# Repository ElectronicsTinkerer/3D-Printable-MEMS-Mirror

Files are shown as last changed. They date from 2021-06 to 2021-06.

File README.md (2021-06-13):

# 3D-Printable-MEMS-Mirror
Files for a 3D-printable MEMS mirror.

## Files
* `models` - SolidWorks files for parts
* `stls` - STL files for printing
* `arduino` - Arduino controller code
* `kicad` - PCB files (and gerbers)

## Online Resources
* [MDPI Books, _MEMS Mirrors_ ](https://www.mdpi.com/books/pdfview/book/611) - Great PDF of a lot of different MEMS mirrors designs and analysis.
* Shopping (For commercial MEMS Mirrors):
  * [Mirrorcle Technologies Inc.](https://www.mirrorcletech.com/wp/products/mems-mirrors/) - Has pricing info
  * [Preciseley Microtechnology Corp.](https://preciseley.com/products/) - Even has development hats for RPi!
  * [Hamamatsu](https://www.hamamatsu.com/us/en/product/optical-components/mems-mirror/index.html)

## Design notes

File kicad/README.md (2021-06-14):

# Axis Drivers for Mirrors

## Interface
### Power
Each board has a 16-30v DC, single rail input. This is the operating voltage of the output amplifiers.

### Output
At the end of the board is the output terminal block to be connected to one of the yoke's deflection coils.

### Digital Interface
At the other end is a parallel interface header for sending data to the DAC. The DAC operates over a 5v interface and all connections have 10k pullup resistors, meaning that unused inputs can be left unconnected. There is a 12-bit parallel data bus, read/write, chip select, reset, and load inputs.

## Output Drive Design
In order to achieve a differential output, two output amplifiers are used, one the inversion of the other around 0.5 * VCC.

## Known Issues
* The heatsinks currently on the KiCad boards are inadequate for the output amplifiers if running at greater than about 0.5A output current. (Active cooling is required)
* The 2.5V regulator's pinning is rotated 120 degrees clockwise from what it should be, so check the datasheet and schematic before soldering. This should be fixed some time in the future.

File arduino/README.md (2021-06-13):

# Arduino Controller for Mirror

## Pin Connections

Pin | Signal Name | Description
--- | --- | ---
`0` | `D0` | Digital 0
`1` | `D1` | Digital 1
`2` | `D2` | Digital 2
`3` | `D3` | Digital 3
`5` | `D5` | Digital 4
`4` | `D4` | Digital 5
`6` | `D6` | Digital 6
`7` | `D7` | Digital 7
`8` | `LD` | Load latch to DAC
`9` | `V_CS` | Select vertical DAC
`10` | `H_CS` | Select horizontal DAC

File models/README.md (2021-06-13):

# MEMS Mirror Design Files

## Files
* `Mirror-Gimbal` - Original 2-axis galvanometer design
* `Mirror-Gimbal-v1.1` - Minor update
* `Mirror-Gimbal-v1.2` - Increased torsion arm length
* `Mirror-Gimbal-v2` - Original 2-axis with vertical magnet mounts
* `Mirror-Gimbal-V3` - Uses quad "O" supports (0.5mm width)
* `Mirror-Gimbal-V3-0.6mm` - Quad "O" supports (0.6mm width)
* `MDD-BoardMount` - Mount for holding deflection driver PCBs and magnetic deflection yoke.

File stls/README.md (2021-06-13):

# MEMS Mirror STLs

## Progression
Photo of each iteration of the mirror gimbal design


## Files
* `Mirror-Gimbal` - Original 2-axis galvanometer design
* `Mirror-Gimbal-v1.1` - Minor update
* `Mirror-Gimbal-v1.2` - Increased torsion arm length
* `Mirror-Gimbal-v2` - Original 2-axis with vertical magnet mounts
* `Mirror-Gimbal-V3` - Uses quad "O" supports (0.5mm width)
* `Mirror-Gimbal-V3-0.6mm` - Quad "O" supports (0.6mm width)
* `MDD-BoardMount` - Mount for holding deflection driver PCBs and magnetic deflection yoke.

## Printer Settings

### Mirror Gimbals
* Initial layer height should be set to `0.25mm`
* Bottom layer should be printed as `concentric`

### Everything Else
* Pretty much whatever works on your printer

## Assembling
The mirror gimbals should be printed with the above settings.
Use superglue to attach a small neodymium magnet to the back (inside) of the central disk on the gimbal. The smaller the magnet, the less mass of the overall system, and thus an increased resonant (and operating) frequency. The disadvantage to a smaller magnet is its weaker magnetic field, meaning that a larger external field must be applied to achieve the same deflection.
For the mirrors, I cut out squares from a dead HDD platter, which were then superglued onto the top of the gimbal's central disk. (For reference, the mirror for gimbal 4C is about 2mm square while 4A's mirror is about 7mm square.)

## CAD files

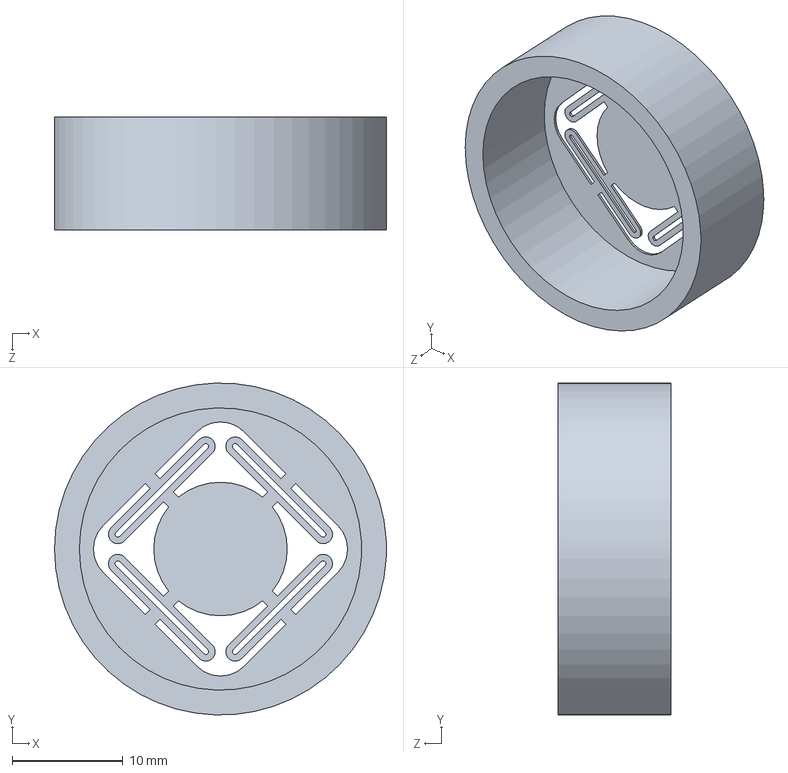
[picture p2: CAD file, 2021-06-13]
models/Mirror-Gimbal-V3.SLDPRT
30.0 x 30.0 x 10.2 mm

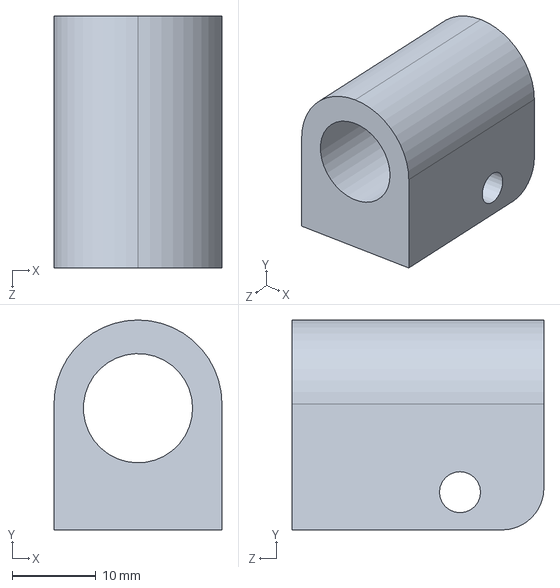
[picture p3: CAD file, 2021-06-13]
models/MDD-LaserHousing.SLDPRT
20.0 x 25.0 x 30.0 mm

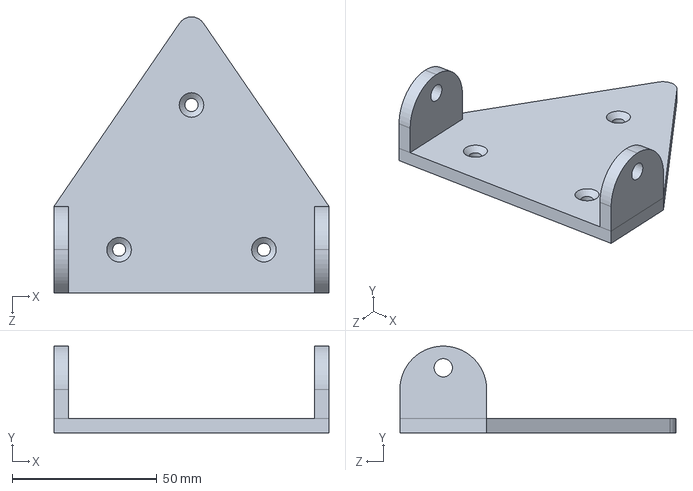
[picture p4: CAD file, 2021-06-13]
models/MDD-Rocker.SLDPRT
95.0 x 30.0 x 95.4 mm

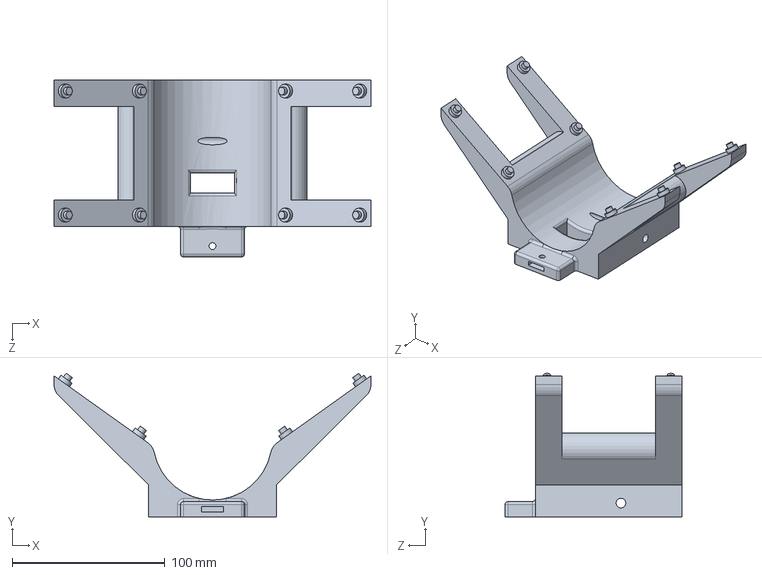
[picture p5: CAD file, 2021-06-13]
models/MDD-BoardMount.SLDPRT
207.8 x 94.2 x 116.0 mm

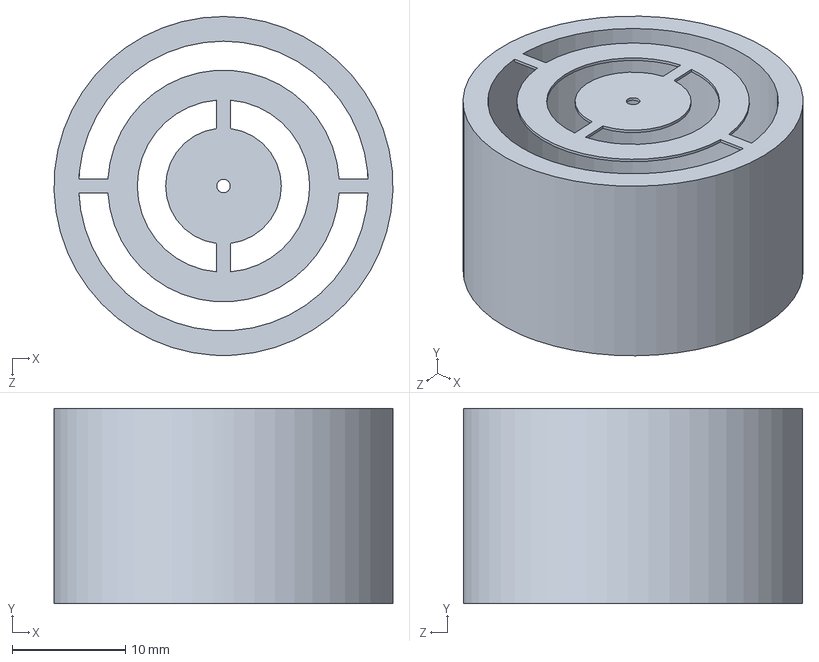
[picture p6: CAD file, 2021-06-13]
models/Mirror-Gimbal.SLDPRT
30.0 x 17.3 x 30.0 mm

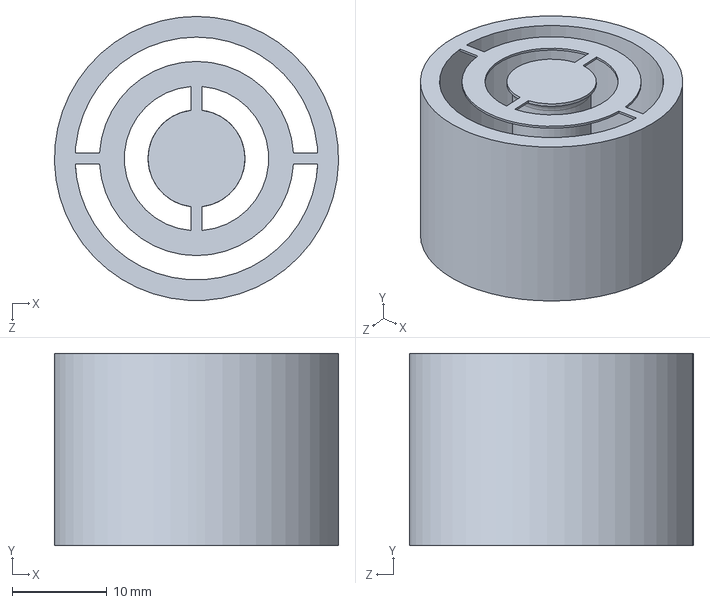
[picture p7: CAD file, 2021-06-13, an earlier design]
models/Mirror-Gimbal-V2.SLDPRT
30.0 x 20.3 x 30.0 mm

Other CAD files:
stls/Mirror-Gimbal-V3-0.6mm.STL
models/Mirror-Gimbal-v1.1.SLDPRT
models/Mirror-Gimbal-v1.2.SLDPRT
stls/MDD-BoardMount.STL
stls/Mirror-Gimbal-V2.STL
stls/Mirror-Gimbal-V3.STL
stls/Mirror-Gimbal-v1.1.STL
stls/Mirror-Gimbal-v1.2.STL
stls/Mirror-Gimbal.STL

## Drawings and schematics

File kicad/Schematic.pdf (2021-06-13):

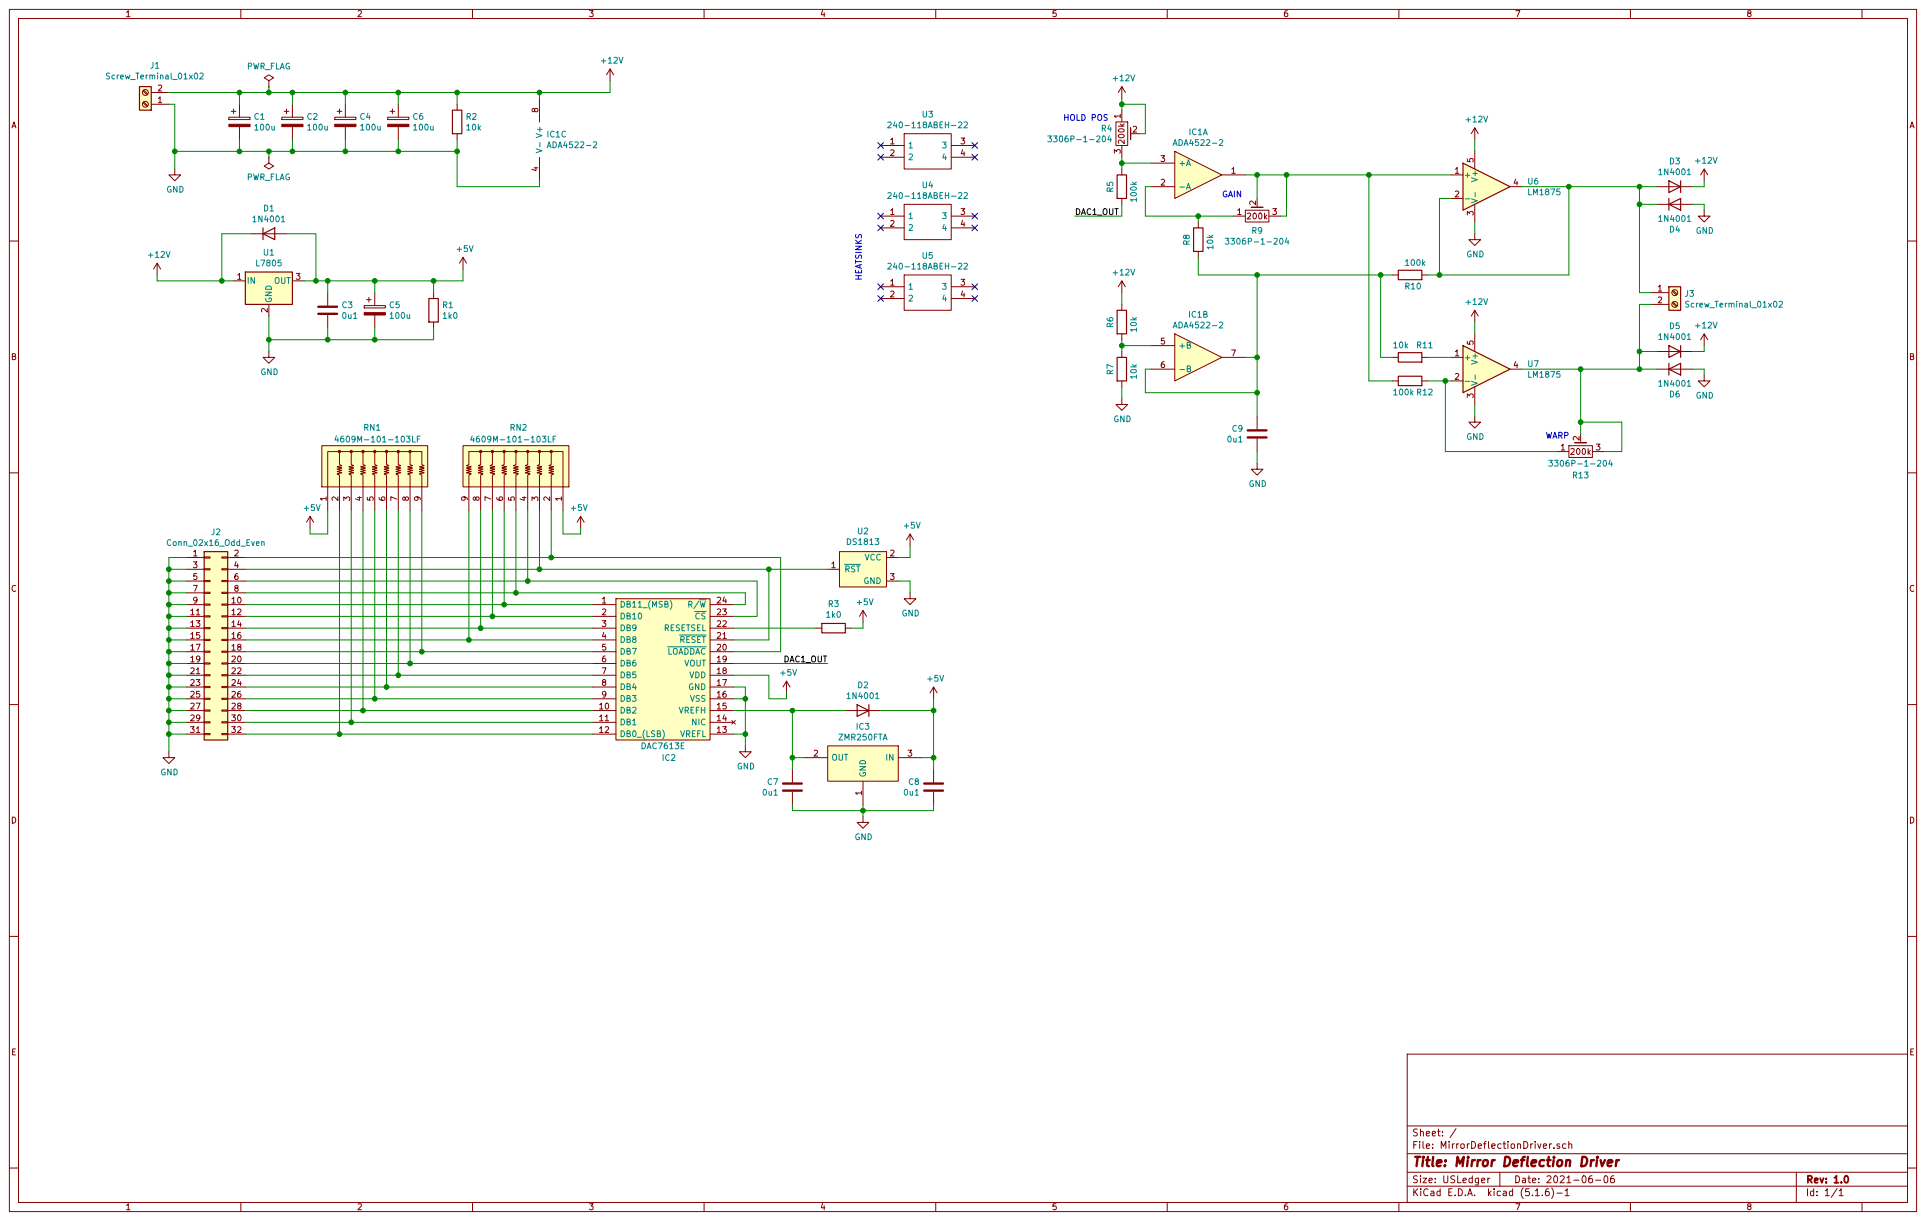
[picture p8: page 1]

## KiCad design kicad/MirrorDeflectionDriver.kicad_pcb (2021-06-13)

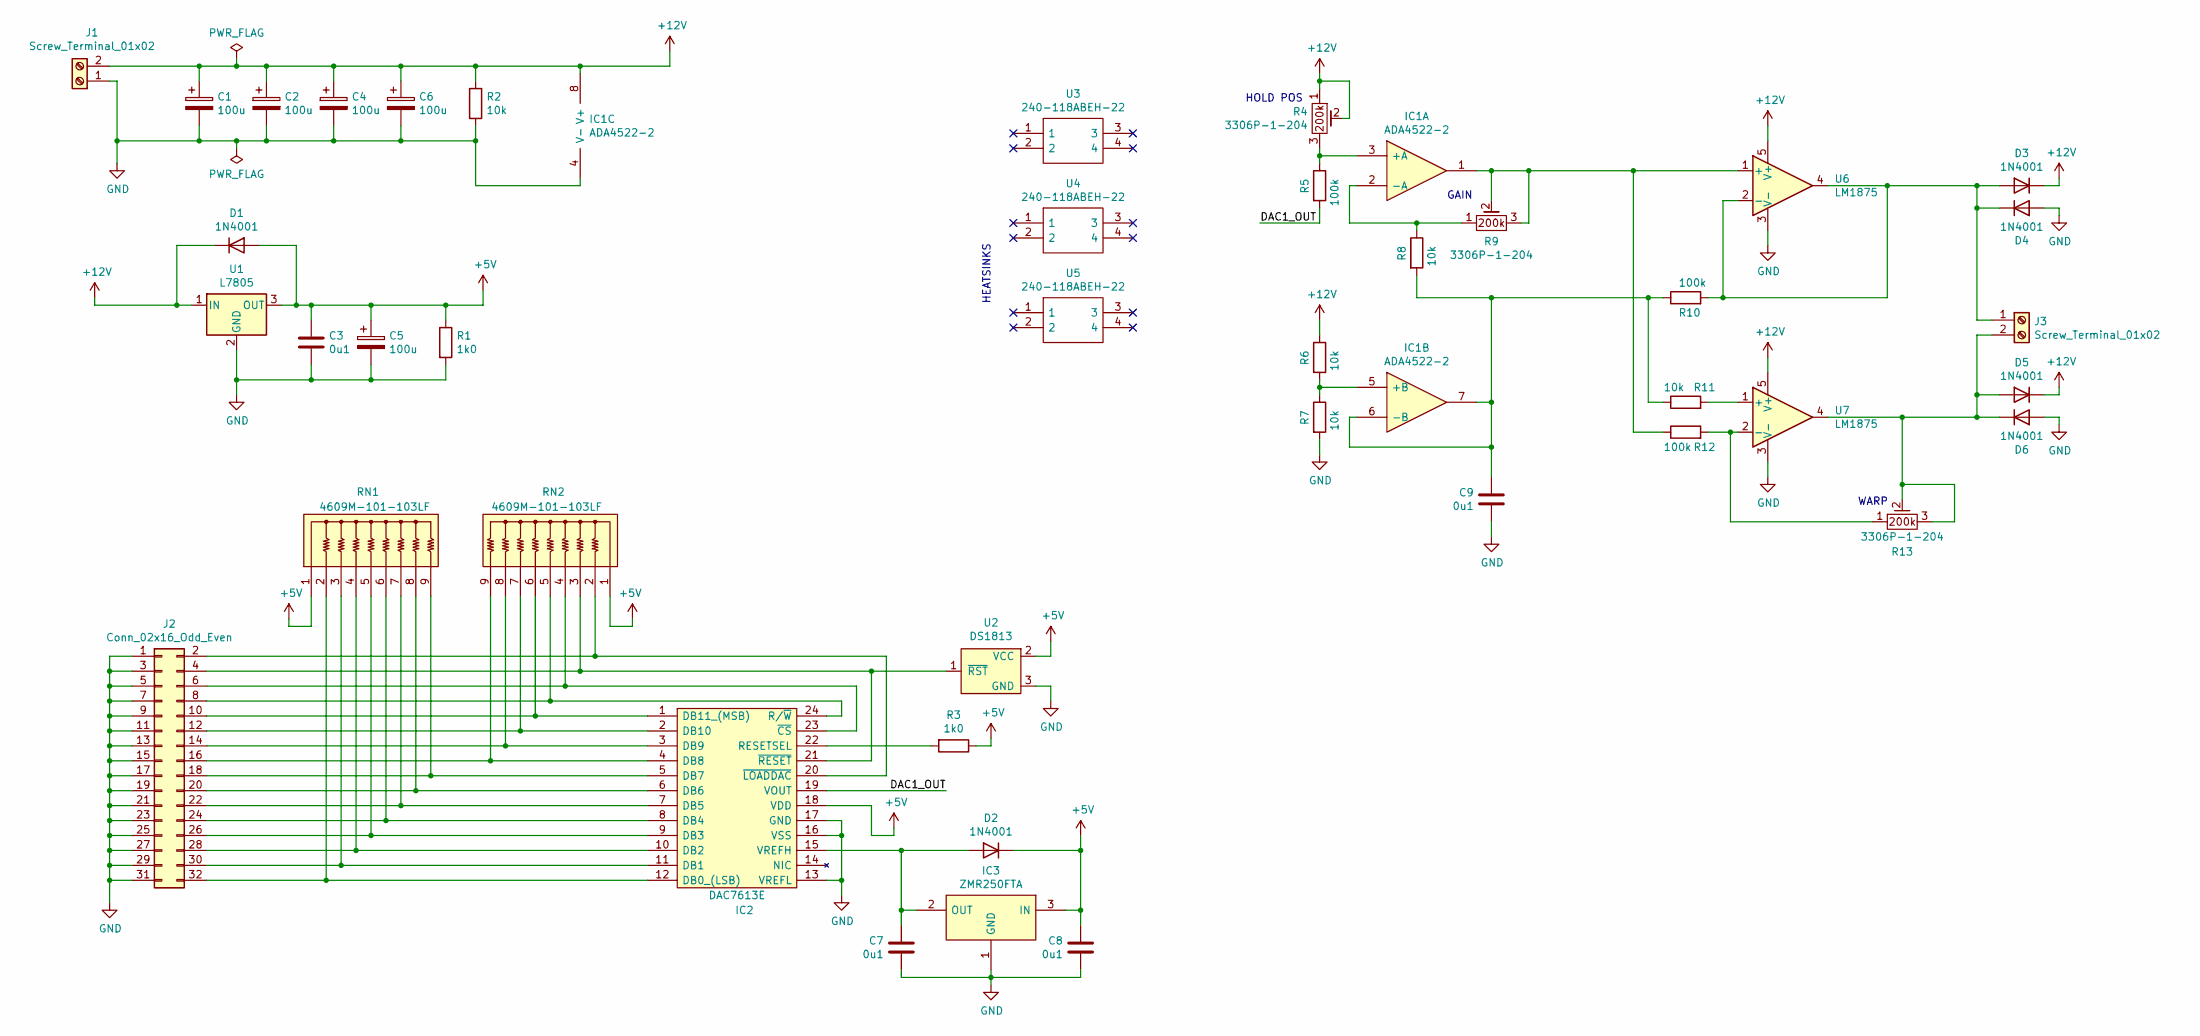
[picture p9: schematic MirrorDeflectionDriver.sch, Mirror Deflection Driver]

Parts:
C1, C2, C4, C5, C6: 100u; CP_Radial_D8.0mm_P3.50mm
C3, C7, C8, C9: 0u1; C_Disc_D4.3mm_W1.9mm_P5.00mm
D1, D2, D3, D4, D5, D6: 1N4001; D_DO-41_SOD81_P10.16mm_Horizontal
IC1: ADA4522-2; MSOP-8_3x3mm_P0.65mm; Mouser Part Number 584-ADA4522-2
IC2: DAC7613E; SOP65P780X200-24N; Mouser Part Number 595-DAC7613E
IC3: ZMR250FTA; SOT96P240X100-3N; Mouser Part Number 522-ZMR250FTA
J1, J3: Screw_Terminal_01x02; TerminalBlock_bornier-2_P5.08mm
J2: Conn_02x16_Odd_Even; PinHeader_2x16_P2.54mm_Vertical
R1, R3: 1k0; R_Axial_DIN0207_L6.3mm_D2.5mm_P7.62mm_Horizontal
R2, R6, R7, R8, R11: 10k; R_Axial_DIN0207_L6.3mm_D2.5mm_P7.62mm_Horizontal
R4, R9, R13: 3306P-1-204; 3306P1204; Mouser Part Number 652-3306P-1-204
R5, R10, R12: 100k; R_Axial_DIN0207_L6.3mm_D2.5mm_P7.62mm_Horizontal
RN1, RN2: 4609M-101-103LF; 4609X; Mouser Part Number 652-4609M-1LF-10K
U1: L7805; TO-126-3_Vertical
U2: DS1813; TO-92
U3, U4, U5: 240-118ABEH-22; 240118ABEH22; Mouser Part Number 567-240-118ABH-22
U6, U7: LM1875; TO-220-5_P3.4x3.7mm_StaggerOdd_Lead3.8mm_Vertical

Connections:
+5V: C3.1, C5.1, C8.1, D1.2 (A), D2.1 (K), IC2.18 (VDD), IC3.3 (IN), R1.1, R3.1, RN1.1, RN2.1, U1.3 (OUT), U2.2 (VCC)
+12V: C1.1, C2.1, C4.1, C6.1, D1.1 (K), D3.1 (K), D5.1 (K), IC1.8 (V+), J1.2, R2.1, R4.1, R4.2, R6.1, U1.1 (IN), U6.5 (V+), U7.5 (V+)
/DAC1_OUT: IC2.19 (VOUT), R5.2
GND: C1.2, C2.2, C3.2, C4.2, C5.2, C6.2, C7.2, C8.2, C9.2, D4.2 (A), D6.2 (A), IC1.4 (V-), IC2.13 (VREFL), IC2.16 (VSS), IC2.17 (GND), IC3.1 (GND), J1.1, J2.1, J2.3, J2.5, J2.7, J2.9, J2.11, J2.13, J2.15, J2.17, J2.19, J2.21, J2.23, J2.25, J2.27, J2.29, J2.31, R1.2, R2.2, R7.2, U1.2 (GND), U2.3 (GND), U6.3 (V-), U7.3 (V-)
unnamed: C7.1, D2.2 (A), IC2.15 (VREFH), IC3.2 (OUT)
unnamed: C9.1, IC1.6 (-B), IC1.7, R8.2, R10.1, R11.1
unnamed: D3.2 (A), D4.1 (K), J3.1, R10.2, U6.2 (-), U6.4
unnamed: D5.2 (A), D6.1 (K), J3.2, R13.2, R13.3, U7.4
unnamed: IC1.1, R9.2, R9.3, R12.1, U6.1 (+)
unnamed: IC1.2 (-A), R8.1, R9.1
unnamed: IC1.3 (+A), R4.3, R5.1
unnamed: IC1.5 (+B), R6.2, R7.1
unnamed: IC2.1 (DB11_(MSB)), J2.10, RN2.6
unnamed: IC2.2 (DB10), J2.12, RN2.7
unnamed: IC2.3 (DB9), J2.14, RN2.8
unnamed: IC2.4 (DB8), J2.16, RN2.9
unnamed: IC2.5 (DB7), J2.18, RN1.9
unnamed: IC2.6 (DB6), J2.20, RN1.8
unnamed: IC2.7 (DB5), J2.22, RN1.7
unnamed: IC2.8 (DB4), J2.24, RN1.6
unnamed: IC2.9 (DB3), J2.26, RN1.5
unnamed: IC2.10 (DB2), J2.28, RN1.4
unnamed: IC2.11 (DB1), J2.30, RN1.3
unnamed: IC2.12 (DB0_(LSB)), J2.32, RN1.2
unnamed: IC2.20 (~LOADDAC), J2.2, RN2.2
unnamed: IC2.21 (~RESET), J2.4, RN2.3, U2.1 (~RST)
unnamed: IC2.22 (RESETSEL), R3.2
unnamed: IC2.23 (~CS), J2.6, RN2.4
unnamed: IC2.24 (R/~W), J2.8, RN2.5
unnamed: R11.2, U7.1 (+)
unnamed: R12.2, R13.1, U7.2 (-)

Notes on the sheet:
GAIN
HOLD POS
WARP
HEATSINKS

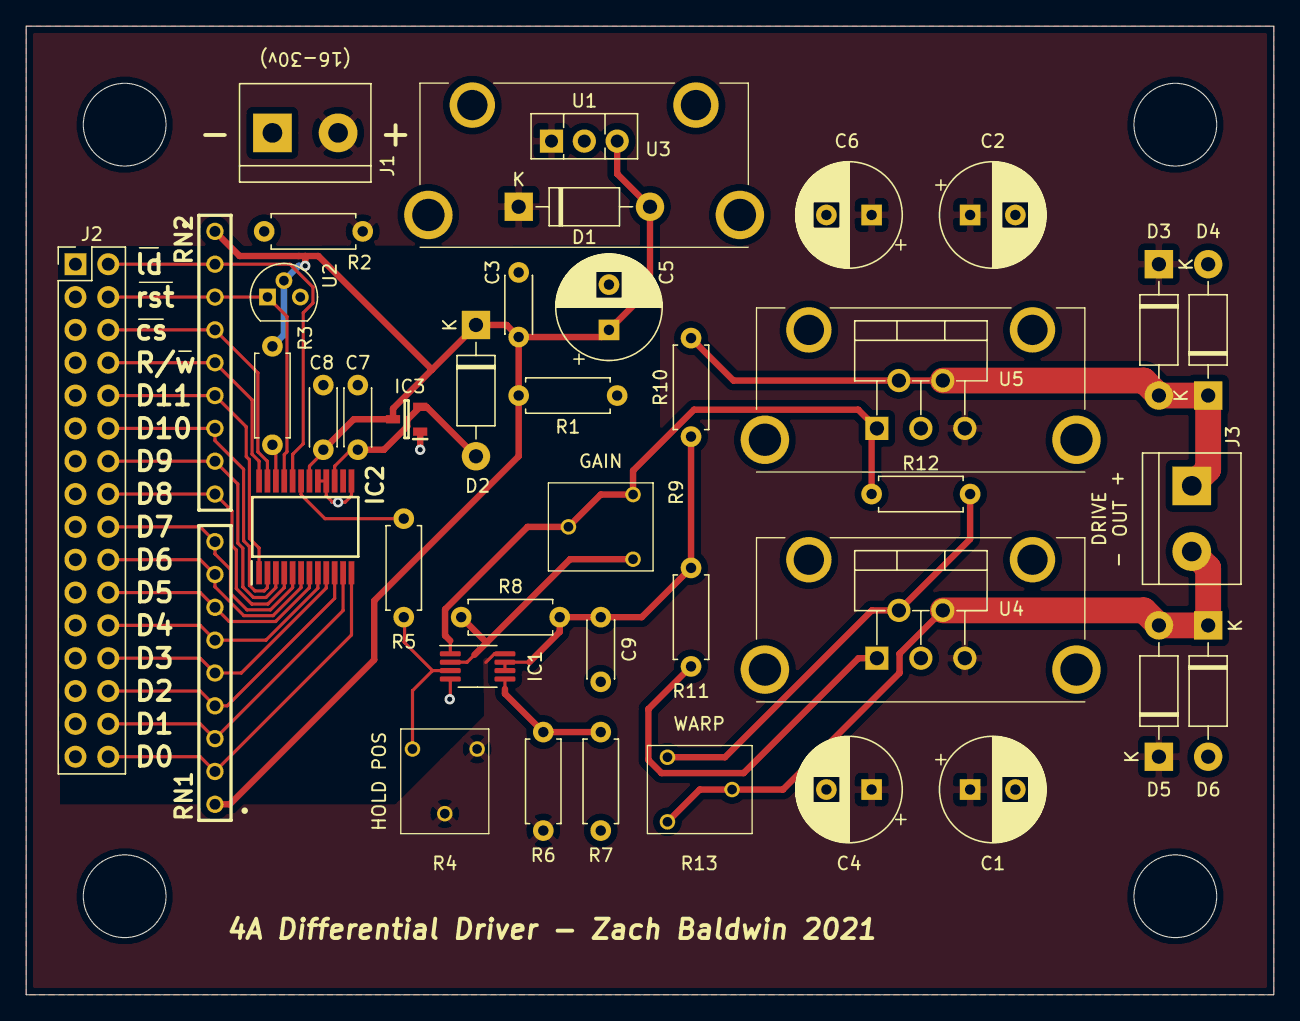
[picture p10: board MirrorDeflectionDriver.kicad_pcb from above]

Board: 2 copper layers, 96.5 x 74.9 mm, 43 parts (0 on the bottom side), 31 nets.

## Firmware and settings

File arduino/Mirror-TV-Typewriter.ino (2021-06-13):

#include <math.h>
#include <stdint.h>

#define VERT 0
#define HORZ 1

#define LD 8
#define V_CS 9
#define H_CS 10

#define STEP_DELAY 1000

#define LETTER_END {0, 0, 0}
#define IS_LETTER_END(li, i) (LETTERS[li][i][0] == 0 && LETTERS[li][i][1] == 0)

const int8_t LETTERS[][8][3] = {
  { {10, 0, 1}, {-10, -10, 1}, {10, 0, 1}, {-10, 10, 1}, LETTER_END }, // Z
  { {10, 0, 1}, {-10, 0, 1}, {0, -10, 1}, {10, 0, 1}, {-10, 0, 1}, {0, 10, 1}, LETTER_END },
  { {10, 0, 1}, {-10,  0, 1}, {10, 10, 1}, {-10, -10, 1}, {0, 10, 1}, {0, -10, 1}, LETTER_END }, // TESTING
  { {10, 10, 1}, {-20, -20, 1}, {10, 10, 1}, {10, 0, 1}, {-10, 0, 1}, LETTER_END },
  { {10, 0, 1}, {-10, -10, 1}, {10, 0, 1}, {-10, 0, 1}, {0, 10, 1}, LETTER_END },
  { {3, 12, 1}, {3, -12, 1}, {-1, 4, 1}, {-4, 0, 1}, {-1, -4, 1}, LETTER_END }, // 5 - SPACESHIP
  { {10, 0, 1}, {0, 10, 1}, {-10, 0, 1}, {0, -10, 1}, LETTER_END }, // 6 - SQUARE
  { {50, 50, 1}, {-50, -50, 1}, LETTER_END }
};

byte letter = 0;
int8_t x_pos = 0, y_pos = 0;

void initDAC() {
  for (int i = 0; i < 8; i++)
    pinMode(i, OUTPUT);
  pinMode(LD, OUTPUT); // /LD signal
  pinMode(V_CS, OUTPUT); // /CS for Vertical
  pinMode(H_CS, OUTPUT); // /CS for Hirizontal
 
  digitalWrite(LD, HIGH);
  digitalWrite(V_CS, HIGH);
  digitalWrite(H_CS, HIGH);
}

void writePos() {
//  Serial.println(y_pos + 0x80, HEX);
  writeAxis(x_pos + 0x80, HORZ);
  writeAxis(y_pos + 0x80, VERT);
    
  digitalWrite(LD, LOW); // LoaD in value to DAC
  delayMicroseconds(1);
  digitalWrite(LD, HIGH);
  delayMicroseconds(1);
}

inline void writeAxis(byte val, byte axis) {
  if (axis == VERT) {
    digitalWrite(V_CS, LOW);
    writeDAC(val);
    digitalWrite(V_CS, HIGH);
  }
  else if (axis == HORZ) {
    digitalWrite(H_CS, LOW);
    writeDAC(val);
    digitalWrite(H_CS, HIGH);
  }
}

inline void writeDAC(byte val) {
  for (int i = 0; i < 8; i++)
    digitalWrite(i, val & (1 << i));
}


// Bresenham's Algorithm (Wikipedia and middle-engine.com)
void nextLetter(byte letter_index) {
  for (uint8_t i = 0; i < 8 && !IS_LETTER_END(letter_index, i); i++) {
    
    int8_t end_x = x_pos + LETTERS[letter_index][i][0];
    int8_t end_y = y_pos + LETTERS[letter_index][i][1];
    
    int8_t dx = abs(LETTERS[letter_index][i][0]);
    int8_t dy = abs(LETTERS[letter_index][i][1]);
    int8_t sx = LETTERS[letter_index][i][0] < 0 ? -1 : 1;
    int8_t sy = LETTERS[letter_index][i][1] < 0 ? -1 : 1;

    int16_t err = 0;

    if (dx > dy) {
      for (; sx < 0 ? x_pos >= end_x : x_pos <= end_x; x_pos += sx) {
        err += dy;
        if (err * 2 >= dx) {
          y_pos += sy;
          err -= dx;
        }
        writePos();
        delayMicroseconds(STEP_DELAY);
      }
    } 
    else {
     for (; sy < 0 ? y_pos >= end_y : y_pos <= end_y; y_pos += sy) {
        err += dx;
        if (err * 2 >= dy) {
          x_pos += sx;
          err -= dy;
        }
        writePos();
        delayMicroseconds(STEP_DELAY);
      } 
    }
  }
}


void setup() {
  // put your setup code here, to run once:
  initDAC();
//  Serial.begin(38400);
}

void loop() {
  // put your main code here, to run repeatedly:
  nextLetter(4);
//  Serial.println(x_pos, HEX);
//  Serial.println(y_pos, HEX);
//  Serial.println("---");
//  x_pos = y_pos = 0;
//  writePos();
//    delay(2000);

}

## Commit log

2021-06-13 Initial addition and organization of design files
    [MDD-BoardMount.SLDPRT, MDD-BoardMount.STL, MDD-LaserHousing.SLDPRT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]
2021-06-14 Added note about regulator layout issue
